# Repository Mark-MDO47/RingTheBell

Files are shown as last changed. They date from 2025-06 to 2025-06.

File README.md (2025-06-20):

# RingTheBell
Demo - use YX5200 to create sounds for the strongman carnival ring the bell game.

**Table Of Contents**
* [Top](#ringthebell "Top")
* [The Idea](#the-idea "The Idea")
  * [ESP32 Over-The-Air Update - OTA](#esp32-over\-the\-air-update-\--ota "ESP32 Over-The-Air Update - OTA")
* [Schematic](#schematic "Schematic")
  * [Nano/Uno - YX5200 PWR at 5V UART at 5V - Works Reliably](#nanouno-\--yx5200-pwr-at-5v-uart-at-5v-\--works-reliably "Nano/Uno - YX5200 PWR at 5V UART at 5V - Works Reliably")
  * [ESP32 - YX5200 PWR at 5V UART at 5V - Works Reliably](#esp32-\--yx5200-pwr-at-5v-uart-at-5v-\--works-reliably "ESP32 - YX5200 PWR at 5V UART at 5V - Works Reliably")
  * [ESP32 - YX5200 PWR at 5V UART at 3.3V - Not Reliable](#esp32-\--yx5200-pwr-at-5v-uart-at-33v-\--not-reliable "ESP32 - YX5200 PWR at 5V UART at 3.3V - Not Reliable")
  * [ESP32 - YX5200 PWR at 3.3V UART at 3.3V - Not Reliable](#esp32-\--yx5200-pwr-at-33v-uart-at-33v-\--not-reliable "ESP32 - YX5200 PWR at 3.3V UART at 3.3V - Not Reliable")
* [Code](#code "Code")
* [Sounds](#sounds "Sounds")
* [Parts List](#parts-list "Parts List")
  * [ESP32 version](#esp32-version "ESP32 version")
  * [Arduino NANO/UNO version](#arduino-nanouno-version "Arduino NANO/UNO version")

## The Idea
[Top](#ringthebell "Top")<br>
This will create sounds for the strongman carnival ring the bell game.

There will be two LOW-active inputs (either from buttons or another processor):
- when the mallet hits to start the weight climbing
- when the weight rings the bell at the top

It is silent until it sees the mallet hit.<br>
Then it starts a rising sound of finite duration.
- If the "ring the bell" input happens while the rising sound is active, the sound is interrupted and the ring the bell sound starts. That sound continues until it finishes.
- If the rising sound finishes before the "ring the bell" sound, then silence until another input happens.

There are two ways to compile, which use different I/O pins:
- as an ESP32 (but not ESP32-S3 which uses different pins; only exception I know)
- as an Arduino Nano or Uno

### ESP32 Over-The-Air Update - OTA
[Top](#ringthebell "Top")<br>
If compiled for an ESP32, the code will include the Over-The-Air Update (OTA) capability. By default, this is implemented so it is always-on, not requiring the ESP-NOW commands from the following descriptions (which are from other projects) nor the optional button push.
- https://github.com/Mark-MDO47/DuelWithBanjos/blob/master/code/DuelWithBanjos/OTA_story.md
- https://github.com/Mark-MDO47/UniRemote/blob/master/code/mdo_use_ota_webupdater/README.md

NOTE: The **Arduino Nano** and **Arduino Uno** do not natively support this OTA capability.

## Schematic
[Top](#ringthebell "Top")<br>
This "schematic wiring diagram" shows connections for both the Arduino Nano and an ESP32 development board.
- I sometimes call my schematics "schematic wiring diagrams" because I don't follow the rules of the standards organizations, although I reserve the right to just call them schematics.
  - I show all the connections as wires and show the pins of chips/modules all together and arranged the same as physical top view instead of separated/organized by function since I use my "schematic" to do the actual wiring of my project.
  - I tend to forget to hook up some of the power and ground connections if I use the standard schematic methods instead of showing the wire.

Notes
- I did not show a switch/button for the ESP32 OTA control signal since the code is configured to automatically prepare that without input
- The 1K resistor in the path to the YX5200 RX line prevents coupling of digital noise into the sound output
- I did not include external power for these prototype designs; I assume they will be powered from the USB
- I have a reliable version for Nano/Uno and for ESP32, plus two ESP32 variations that do now work reliably
  - The reliable ESP32 variation uses a SN74HCT125N to do voltage level translation for the UART interface
  - I am using resistors to drop the voltage from YX5200 5V to ESP32 3.3V (to avoid damage to ESP32)

### Nano/Uno - YX5200 PWR at 5V UART at 5V - Works Reliably
[Top](#ringthebell "Top")<br>
Here with a Nano/Uno and with the YX5200 using 5V for power and 5V on the UART interface - works reliably.<br>
```
// NANO (and UNO) pin definitions:
//
// Control inputs for Sound Processing - these two are GPIO pins with internal pull-up capability
//   NANO (or UNO) pin D-04   DPIN_MALLET_HIT  when it goes LOW
//   NANO (or UNO) pin D-06   DPIN_RING_BELL   when it goes LOW
//
// YX5200/DFPlayer Sound Player
//   NANO (or UNO) pin D-10   DPIN_SRL_RX   Arduino RX; YX5200 TX - 9600 Baud
//   NANO (or UNO) pin D-11   DPIN_SRL_TX   Arduino TX; YX5200 RX - 9600 Baud
//   NANO (or UNO) pin D-12   DPIN_AUDIO_BUSY YX5200 BUSY; HIGH when audio finishes
```
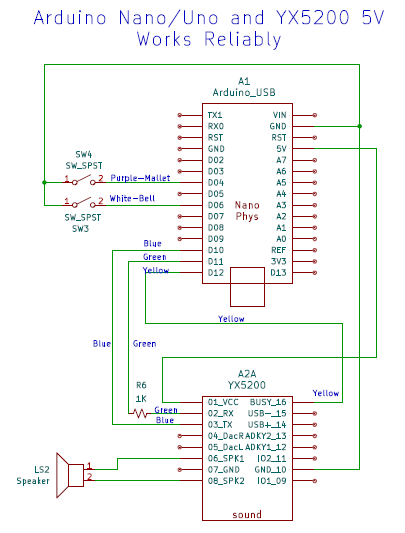
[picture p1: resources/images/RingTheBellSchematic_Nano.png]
Ring the Bell Schematic with Nano - works reliably


### ESP32 - YX5200 PWR at 5V UART at 5V - Works Reliably
[Top](#ringthebell "Top")<br>
Here with an ESP32 and with the YX5200 using 5V for power and 5V on the UART interface - works reliably.<br>
```
// ESP32 pin definitions:
//    NOTE: these are good pins for most ESP32 - see https://randomnerdtutorials.com/esp32-pinout-reference-gpios/
//    If using an ESP32-S3, see https://randomnerdtutorials.com/esp32-s3-devkitc-pinout-guide/ and make any
//       needed adjustments.
//
// Control inputs for Sound Processing - these two are GPIO pins with internal pull-up capability
//   ESP32 Dev Module pin D-13   DPIN_MALLET_HIT  when it goes LOW
//   ESP32 Dev Module pin D-27   DPIN_RING_BELL   when it goes LOW
// 
// YX5200/DFPlayer Sound Player
//   ESP32 Dev Module pin D-16   DPIN_SRL_RX   Arduino RX; YX5200 TX - 9600 Baud
//   ESP32 Dev Module pin D-17   DPIN_SRL_TX   Arduino TX; YX5200 RX - 9600 Baud
//   ESP32 Dev Module pin D-23   DPIN_AUDIO_BUSY YX5200 BUSY; HIGH when audio finishes
```
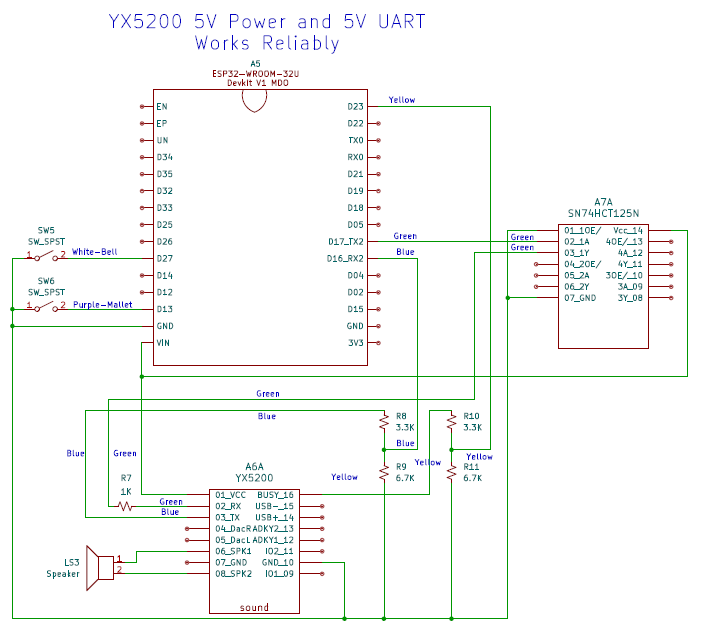
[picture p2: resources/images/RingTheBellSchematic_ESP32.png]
Ring the Bell Schematic with ESP32; YX5200 5V Power 5V UART - Works Reliably


### ESP32 - YX5200 PWR at 5V UART at 3.3V - Not Reliable
[Top](#ringthebell "Top")<br>
Here with an ESP32 and with the YX5200 using 5V for power and 3.3V on the UART interface - not reliable. The YX5200 often ignores commands from the ESP32.<br>
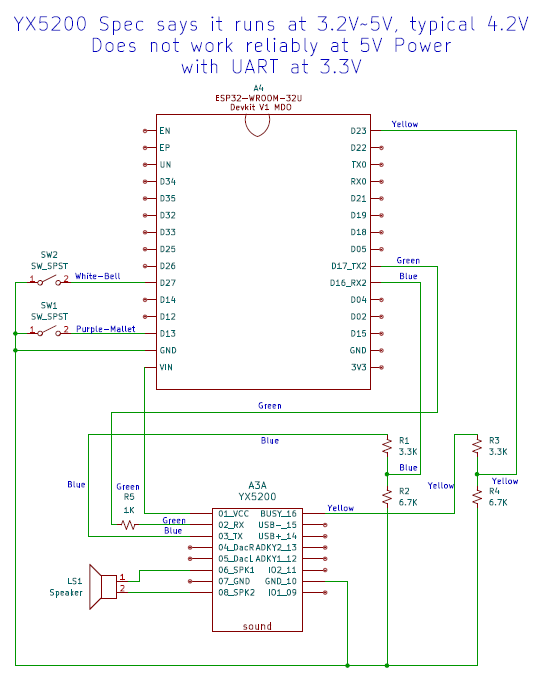
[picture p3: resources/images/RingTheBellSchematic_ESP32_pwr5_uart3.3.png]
Ring the Bell Schematic with ESP32; YX5200 5V Power 3.3V UART - Not Reliable


### ESP32 - YX5200 PWR at 3.3V UART at 3.3V - Not Reliable
[Top](#ringthebell "Top")<br>
Here with an ESP32 and with the YX5200 using 3.3V for power and 3.3V on the UART interface - not reliable. The YX5200 often ignores commands from the ESP32.<br>
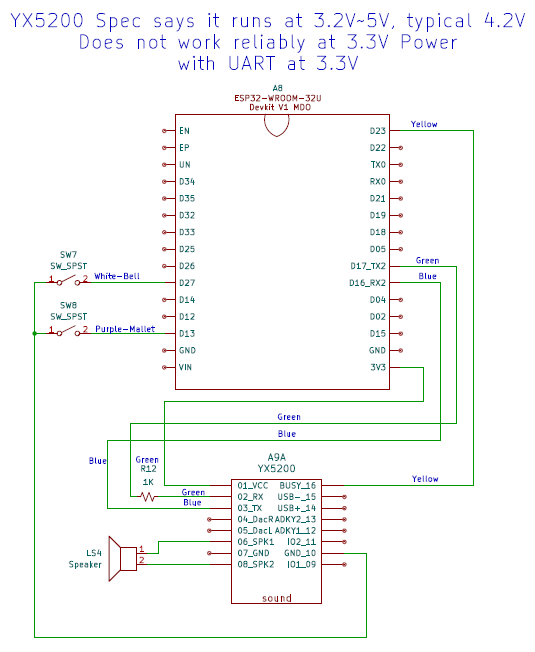
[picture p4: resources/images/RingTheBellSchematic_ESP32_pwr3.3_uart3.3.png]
Ring the Bell Schematic with ESP32; YX5200 3.3V Power 3.3V UART - Not Reliable


## Code
[Top](#ringthebell "Top")<br>
The code is in the ./code/ area split into several directories. The *.ino file is in ./code/RingTheBell/RingTheBell.ino.<br>
A directory of the code can be found here:
- https://github.com/Mark-MDO47/RingTheBell/tree/master/code

## Sounds
[Top](#ringthebell "Top")<br>
The sounds and a description of how to create/adjust sounds and how to copy them to the MicroSD card for the YX5200 can be found here:<br>
- https://github.com/Mark-MDO47/RingTheBell/blob/master/resources/sounds/README.md

## Parts List
[Top](#ringthebell "Top")<br>

### ESP32 version
[Top](#ringthebell "Top")<br>

| Title | Descrip | URL | each |
| --- | --- | --- | --- |
| ESP32 | 1 @ ESP32 Devkit V1 ESP-WROOM-32 (or just about any ESP32 WiFi capable module **except an ESP-32-S3**) | https://www.amazon.com/Hosyond-ESP-WROOM-32-Development-Microcontroller-Compatible/dp/B0C7C2HQ7P/ref=sr_1_4 | $3.50 |
| YX5200 | 1 @ Sound Module with MicroSD (TF) card socket | https://www.amazon.com/Organizer-YX5200-DFPlayer-Supporting-Arduino/dp/B07XXYQBNS/ref=sr_1_1 | $2.00 |
| MicroSD card | 1 @ 32GByte or smaller MicroSD card formatted as FAT32; shown is 16GB example | https://www.amazon.com/dp/B08KSSX9PH | $3.75 |
| speaker |  Metal Shell Round Internal Magnet Speaker 2W 8 Ohm approx 1 inch | https://www.amazon.com/dp/B0177ABRQ6 | $2.80 |
| resistors | 1 @ 1.0-KOhm 1/4 watt through-hole resistors | https://www.digikey.com/en/products/detail/stackpole-electronics-inc/CF14JT1K00/1741314 | $0.10 |
| resistors | 2 @ 3.3-KOhm 1/4 watt through-hole resistors | https://www.digikey.com/en/products/detail/stackpole-electronics-inc/CF14JT3K30/1741376 | $0.10 |
| resistors | 2 @ 6.65-KOhm 1/4 watt through-hole resistors | https://www.digikey.com/en/products/detail/stackpole-electronics-inc/RNF14FTD6K65/1682364 | $0.10 |
| SN74HCT125N | 1 @ Non-inverting 5.5V buffer 14-pin DIP | https://www.digikey.com/en/products/detail/texas-instruments/SN74HCT125N/376860 | $0.63 |

### Arduino NANO/UNO version
[Top](#ringthebell "Top")<br>

| Title | Descrip | URL | each |
| --- | --- | --- | --- |
| NANO | Arduino NANO (or UNO) or clone | https://www.aliexpress.us/item/3256805941736729.html | $1.40 |
| YX5200 | 1 @ Sound Module with MicroSD (TF) card socket | https://www.amazon.com/Organizer-YX5200-DFPlayer-Supporting-Arduino/dp/B07XXYQBNS/ref=sr_1_1 | $2.00 |
| MicroSD card | 1 @ 32GByte or smaller MicroSD card formatted as FAT32; shown is 16GB example | https://www.amazon.com/dp/B08KSSX9PH | $3.75 |
| speaker |  Metal Shell Round Internal Magnet Speaker 2W 8 Ohm approx 1 inch | https://www.amazon.com/dp/B0177ABRQ6 | $2.80 |
| resistors | 1 @ 1.0-KOhm 1/4 watt through-hole resistors | https://www.digikey.com/en/products/detail/stackpole-electronics-inc/CF14JT1K00/1741314 | $0.10 |

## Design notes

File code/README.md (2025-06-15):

# Code

**Table Of Contents**
* [Top](#code "Top")
* [Introduction](#introduction "Introduction")
* [RingTheBell](#ringthebell "RingTheBell")
* [lib_commonDFcode](#lib_commondfcode "lib_commonDFcode")
* [lib_DFPlayerMini](#lib_dfplayermini "lib_DFPlayerMini")
* [lib_mdo_use_ota](#lib_mdo_use_ota "lib_mdo_use_ota")

## Introduction
[Top](#code "Top")<br>
The code is divided into several subdirectories as shown below<br>
| Directory | Description |
| --- | --- |
| [code/RingTheBell](https://github.com/Mark-MDO47/RingTheBell/tree/master/code/RingTheBell "RingTheBell - the *.ino containing #defines to define compile options") | The *.ino file for RingTheBell.<br>  Has #define statements to control choice of Arduino NANO/UNO or ESP32 target.<br>  **void DFsetup_pins_serial()** - defines pins and inits serial port for YX5200 DFPlayer. Includes code that handles SoftwareSerial for Arduino NANO/UNO and Hardware Serial for ESP32. |
| [code/lib_commonDFcode](https://github.com/Mark-MDO47/RingTheBell/tree/master/code/lib_commonDFcode "lib_commonDFcode") | lib_commonDFcode - This is where (almost all) the routines are that I wrote to handle calls to DFPlayerMini. Significant ones are<br>  **void DFsetup()** - call after calling **DFsetup_pins_serial**; will set baud rate to 9600 internally, choose SD card operation, and set default volume.<br>  **void  DFstartSound(uint16_t p_SoundNum, uint16_t p_Volume)** - starts requested *.wav file, interrupting any playing sound file. Also sets volume level.<br>  **uint8_t DFcheckSoundDone()** - returns TRUE if previous sound is complete. Takes into account that HW BUSY signal may not start until >=40 milliseconds after DFstartSound(). |
| [code/lib_DFPlayerMini](https://github.com/Mark-MDO47/RingTheBell/tree/master/code/lib_DFPlayerMini "lib_DFPlayerMini") | lib_DFPlayerMini - The source code for the DFRobot driver for the DFPlayer module.<br>  Available with Arduino IDE but I did a lot of debugging over the years inserting modified code here so I just always include it.<br>  Has its own separate license in file LICENSE_for_DFRobot_code.txt |
| [code/lib_mdo_use_ota](https://github.com/Mark-MDO47/RingTheBell/tree/master/code/lib_mdo_use_ota "lib_mdo_use_ota") | lib_mdo_use_ota - My ESP32 Over-The-Air Update (OTA) code to make it easy to use OTA.<br>  Originally from https://github.com/Mark-MDO47/UniRemote/tree/master/code/mdo_use_ota_webupdater |

## RingTheBell
[Top](#code "Top")<br>

### ESP32 Over-The-Air Update - OTA
[Top](#code "Top")<br>
If compiled for an ESP32, the code will include the Over-The-Air Update (OTA) capability. By default, this is implemented so it is always-on, not requiring the ESP-NOW commands from the following descriptions (which are from other projects) nor the optional button push.
- https://github.com/Mark-MDO47/DuelWithBanjos/blob/master/code/DuelWithBanjos/OTA_story.md
- https://github.com/Mark-MDO47/UniRemote/blob/master/code/mdo_use_ota_webupdater/README.md

ESP32 OTA compilation is controlled by the following **#define** statements in **RingTheBell.ino**
```C
#define MDO_USE_OTA  1 // zero to not use, non-zero to use OTA ESP32 Over-The-Air software updates
#define FORCE_OTA_ON_IF 1 // ESP32: non-zero to force OTA to be on always without needing the pin ONLY if MDO_USE_OTA is also on
```

If you want to compile for ESP32 with OTA enabled you need to create a file **gitignore_wifi_key.h** with the following definitions (I suggest using the ".gitignore" file so this does not accidentally show up in your public repository; see below after the #define statements).
```C
#define WIFI_PWD "password for your local wifi"
#define WIFI_SSID "SSID for your local WiFi"
#define WIFI_OTA_WEB_USR "username to be able to do OTA"
#define WIFI_OTA_WEB_PWD "password to be able to do OTA"
```

You could optionally add this line at the end of your **.gitignore** file to prevent any file or directory starting with gitignore from being saved to the repository. Can save some embarassment.
```
gitignore*
```

NOTE: The **Arduino Nano** and **Arduino Uno** do not natively support this OTA capability.

## lib_commonDFcode
[Top](#code "Top")<br>

## lib_DFPlayerMini
[Top](#code "Top")<br>

## lib_mdo_use_ota
[Top](#code "Top")<br>
This code is an attempt to make the ESP32 Over-The-Air Update (OTA) capability easy to use. It comes from my UniRemote project. Details can be found here:
- https://github.com/Mark-MDO47/UniRemote/tree/master/code/mdo_use_ota_webupdater

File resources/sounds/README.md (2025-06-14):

# Ring the Bell Sounds

**Table Of Contents**
* [Top](#ring-the-bell-sounds "Top")
* [Audacity](#audacity "Audacity")
* [FreeSound](#freesound "FreeSound")
* [YX5200 DFplayer](#yx5200-dfplayer "YX5200 DFplayer")
* [Creating and Modifying Sound Files](#creating-and-modifying-sound-files "Creating and Modifying Sound Files")
  * [Generate Chirp](#generate-chirp "Generate Chirp")
  * [After Generate Chirp](#after-generate-chirp "After Generate Chirp")
  * [Export Chirp](#export-chirp "Export Chirp")
  * [Generate Silence](#generate-silence "Generate Silence")
  * [Export Silence](#export-silence "Export Silence")
  * [Import Mr. Fossy](#import-mr-fossy "Import Mr. Fossy")
  * [Export Mr. Fossy](#export-mr-fossy "Export Mr. Fossy")
* [Copy the Files to MicroSD Card](#copy-the-files-to-microsd-card "Copy the Files to MicroSD Card")

## Audacity
[Top](#ring-the-bell-sounds "Top")<br>
I used Audacity to create and/or manipulate the sound files to a format usable by the YX5200 audio chip.
- https://www.audacityteam.org/

## FreeSound
[Top](#ring-the-bell-sounds "Top")<br>
I obtained one file from FreeSound that I didn't create with Audacity.
- https://freesound.org

This sound was SFX_STICKERRIPPER_foilBooms_01.wav found at https://freesound.org/people/MrFossy/sounds/590360/. It was generated by a user named "MrFossy".
- I will refer to any sound file with a derivation from this sound by the name "Mr. Fossy".
- In the text relating to this file on FreeSound it says
```
Feel free to use my sounds for any commercial/noncommercial purpose without attribution.
 (I wouldn't object to being credited, however!)
```

Thank you MrFossy!

## YX5200 DFplayer
[Top](#ring-the-bell-sounds "Top")<br>
Using the YX5200 to read the sound files and drive the 8-ohm speaker.

This repo has a lot of info on making .wav files that are suitable for the YX5200. I use .wav instead of .mp3 both because it works better with more clones of the YX5200 and because there is a noticeable start-up delay with .mp3 files.
- https://github.com/Mark-MDO47/AudioPlayer-YX5200

## Creating and Modifying Sound Files
[Top](#ring-the-bell-sounds "Top")<br>

### Generate Chirp
[Top](#ring-the-bell-sounds "Top")<br>
Menu: **Generate** ==> **Chirp...** then use the settings shown.<br>
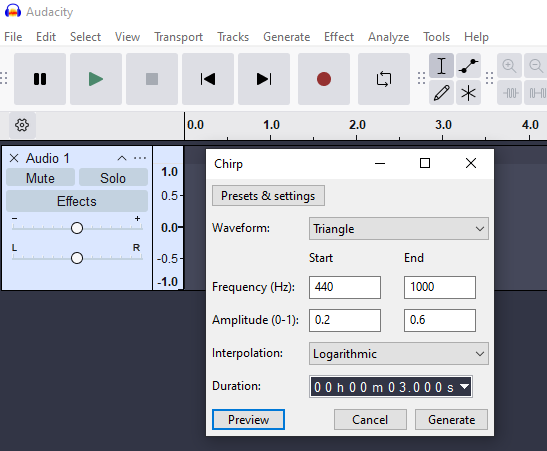
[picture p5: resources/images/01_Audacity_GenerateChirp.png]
Audacity Generate Chirp


### After Generate Chirp
[Top](#ring-the-bell-sounds "Top")<br>
You can see the gradual crescendo.<br>
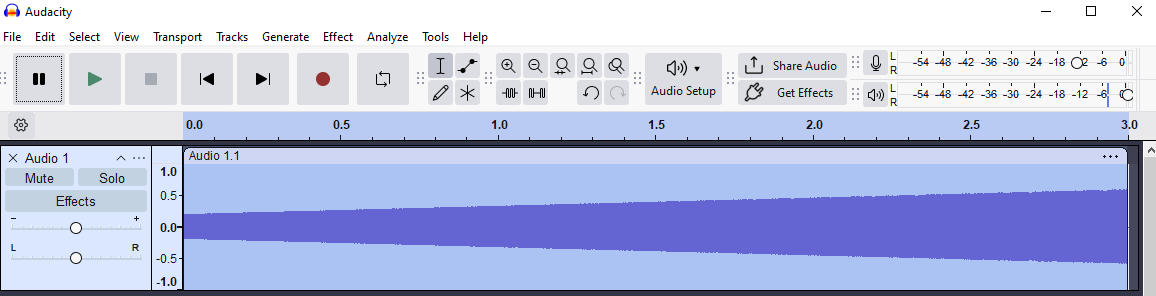
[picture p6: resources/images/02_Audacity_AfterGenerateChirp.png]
Audacity After Generate Chirp


### Export Chirp
[Top](#ring-the-bell-sounds "Top")<br>
We save it as a 22050 Hz mono .wav file; see https://github.com/Mark-MDO47/AudioPlayer-YX5200 for the reason.<br>
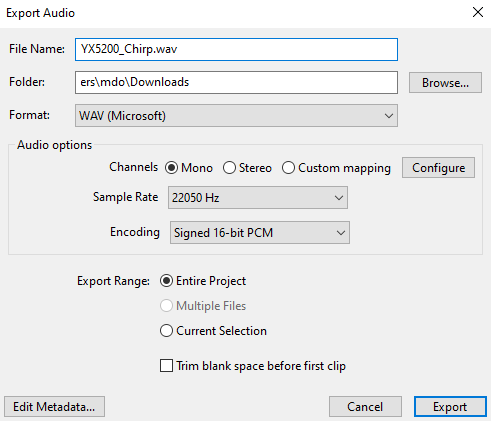
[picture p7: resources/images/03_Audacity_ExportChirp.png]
Audacity Export Chirp.png


### Generate Silence
[Top](#ring-the-bell-sounds "Top")<br>
Menu: **Generate** ==> **Silence...** then use the settings shown.<br>
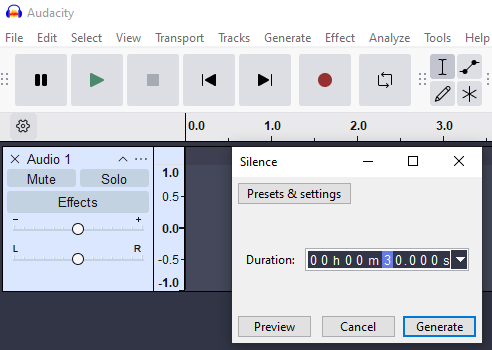
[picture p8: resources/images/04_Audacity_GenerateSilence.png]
Audacity Generate Silence


### Export Silence
[Top](#ring-the-bell-sounds "Top")<br>
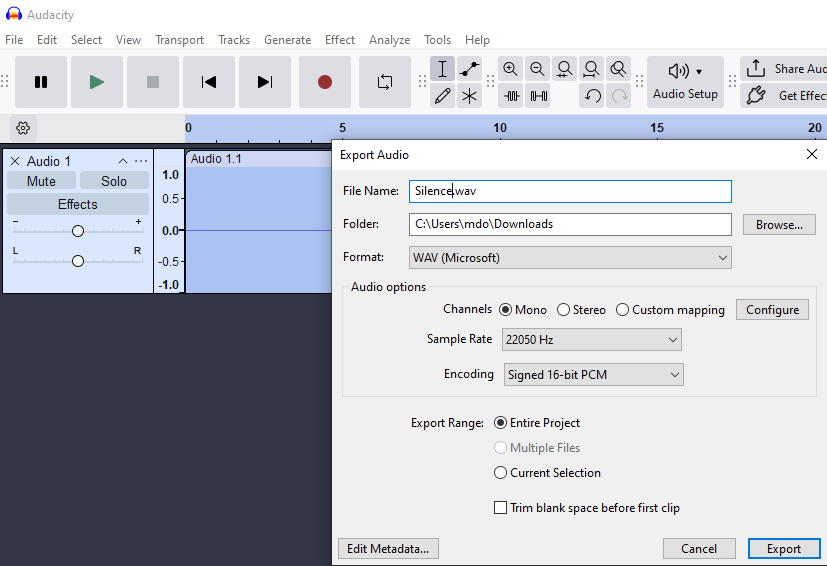
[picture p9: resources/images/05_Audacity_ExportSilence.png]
Audacity Export Silence


### Import Mr. Fossy
[Top](#ring-the-bell-sounds "Top")<br>
Menu: **File** ==> **Import** ==> **Audio...** and choose the file.<br>
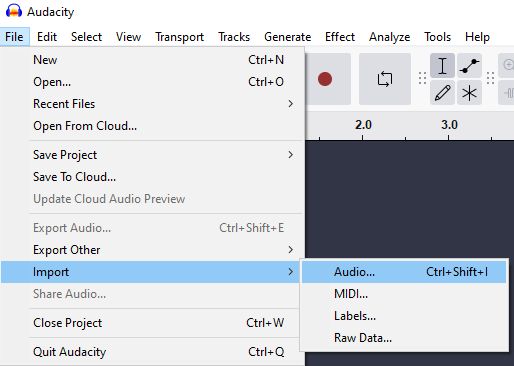
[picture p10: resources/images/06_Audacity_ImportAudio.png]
Audacity Import Mr. Fossy Audio


### Export Mr. Fossy
[Top](#ring-the-bell-sounds "Top")<br>
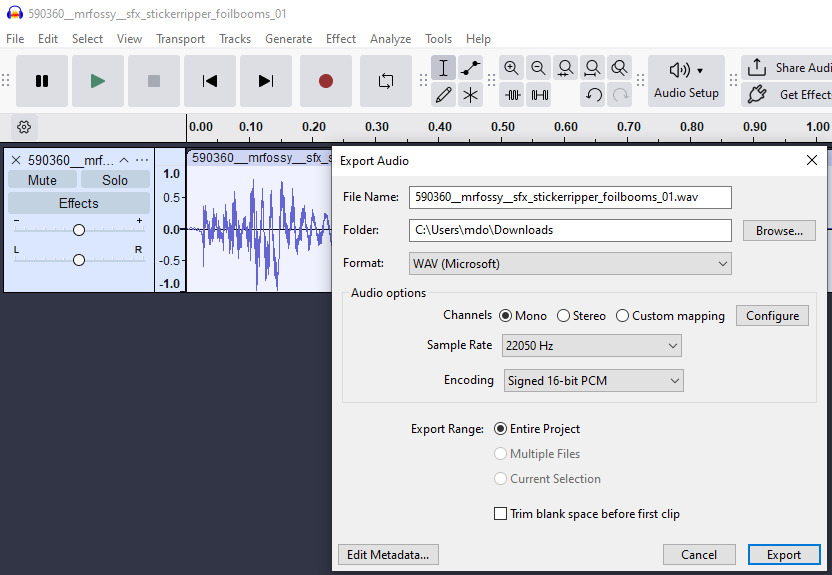
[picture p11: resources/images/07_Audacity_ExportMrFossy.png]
Audacity Export Mr. Fossy Audio


## Copy the Files to MicroSD Card
[Top](#ring-the-bell-sounds "Top")<br>
The MicroSD card **must** be freshly formatted as FAT32; see https://github.com/Mark-MDO47/AudioPlayer-YX5200

Also from that reference, use copyem.py to create a list of commands to copy the files in correct order onto the MicroSD card.
- I use GIT bash on Windows to do this; my script is run_copyem.sh which assumes
  - the freshly FAT32-formatted MicroSD card is mounted as H: (Windows)
  - I am running the script from the directory containing the .wav files
  - that same directory contains Attributions.html file that I want stored on the MicroSD card
  - I want the output as a bash script not a Windows .bat format
  - once again, I suggest you look at https://github.com/Mark-MDO47/AudioPlayer-YX5200 for more details

You could either just let the commands show up on the screen and copy/paste them back into the GIT bash screen, but run_copyem.sh redirects them to file copy_files.sh.

Here is what my script run_copyem.sh looks like:<br>
```
python /d/github-Mark-MDO47/AudioPlayer-YX5200/copyem.py -d . -s H: -f 0003_YX5200_Silence.wav -l > copy_files.sh
```

Here is what the output script copy_files.sh looks like:<br>
```
cp ./0001_yx5200_chirp.wav H:/001.wav
cp ./0002_yx5200_mrfossy__sfx_stickerripper_foilbooms_01.wav H:/002.wav
cp ./0003_yx5200_silence.wav H:/003.wav

mkdir H:/ATTRIBUTIONS
cp  ./Attributions.html H:/ATTRIBUTIONS
```

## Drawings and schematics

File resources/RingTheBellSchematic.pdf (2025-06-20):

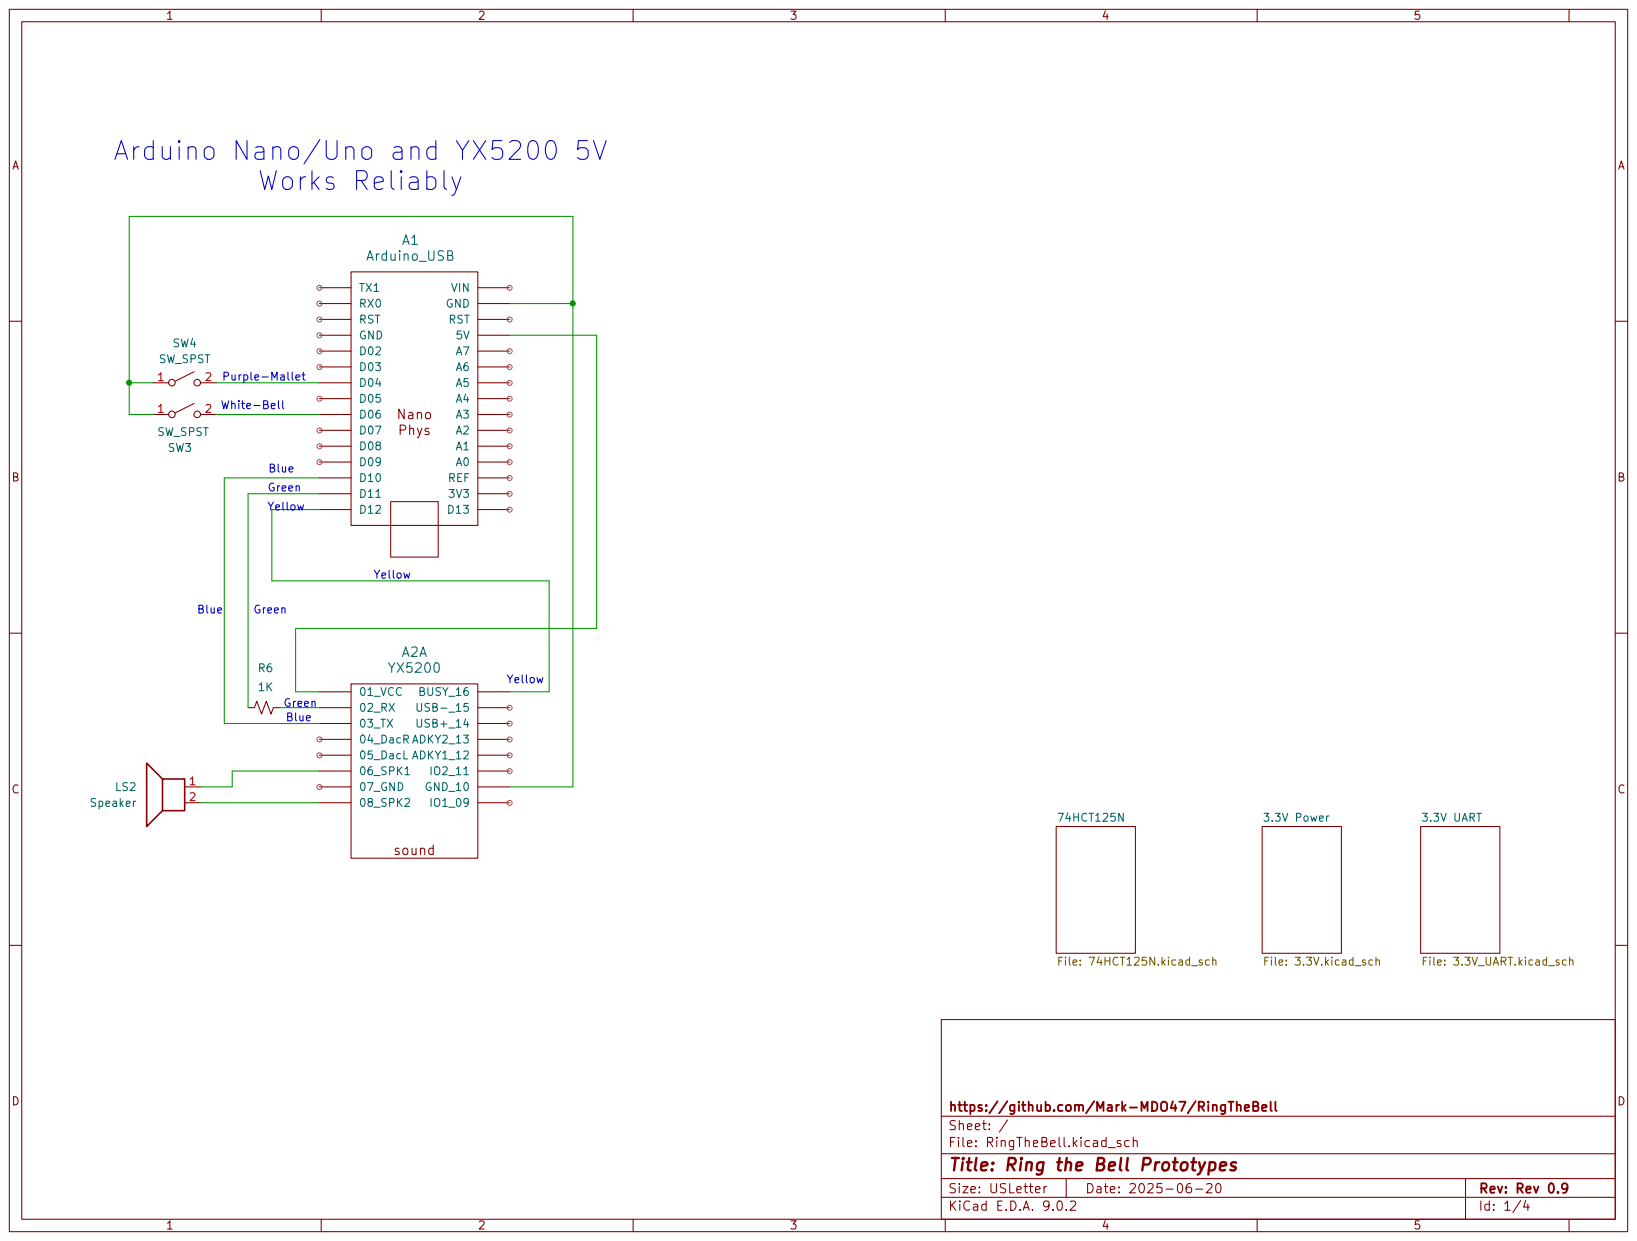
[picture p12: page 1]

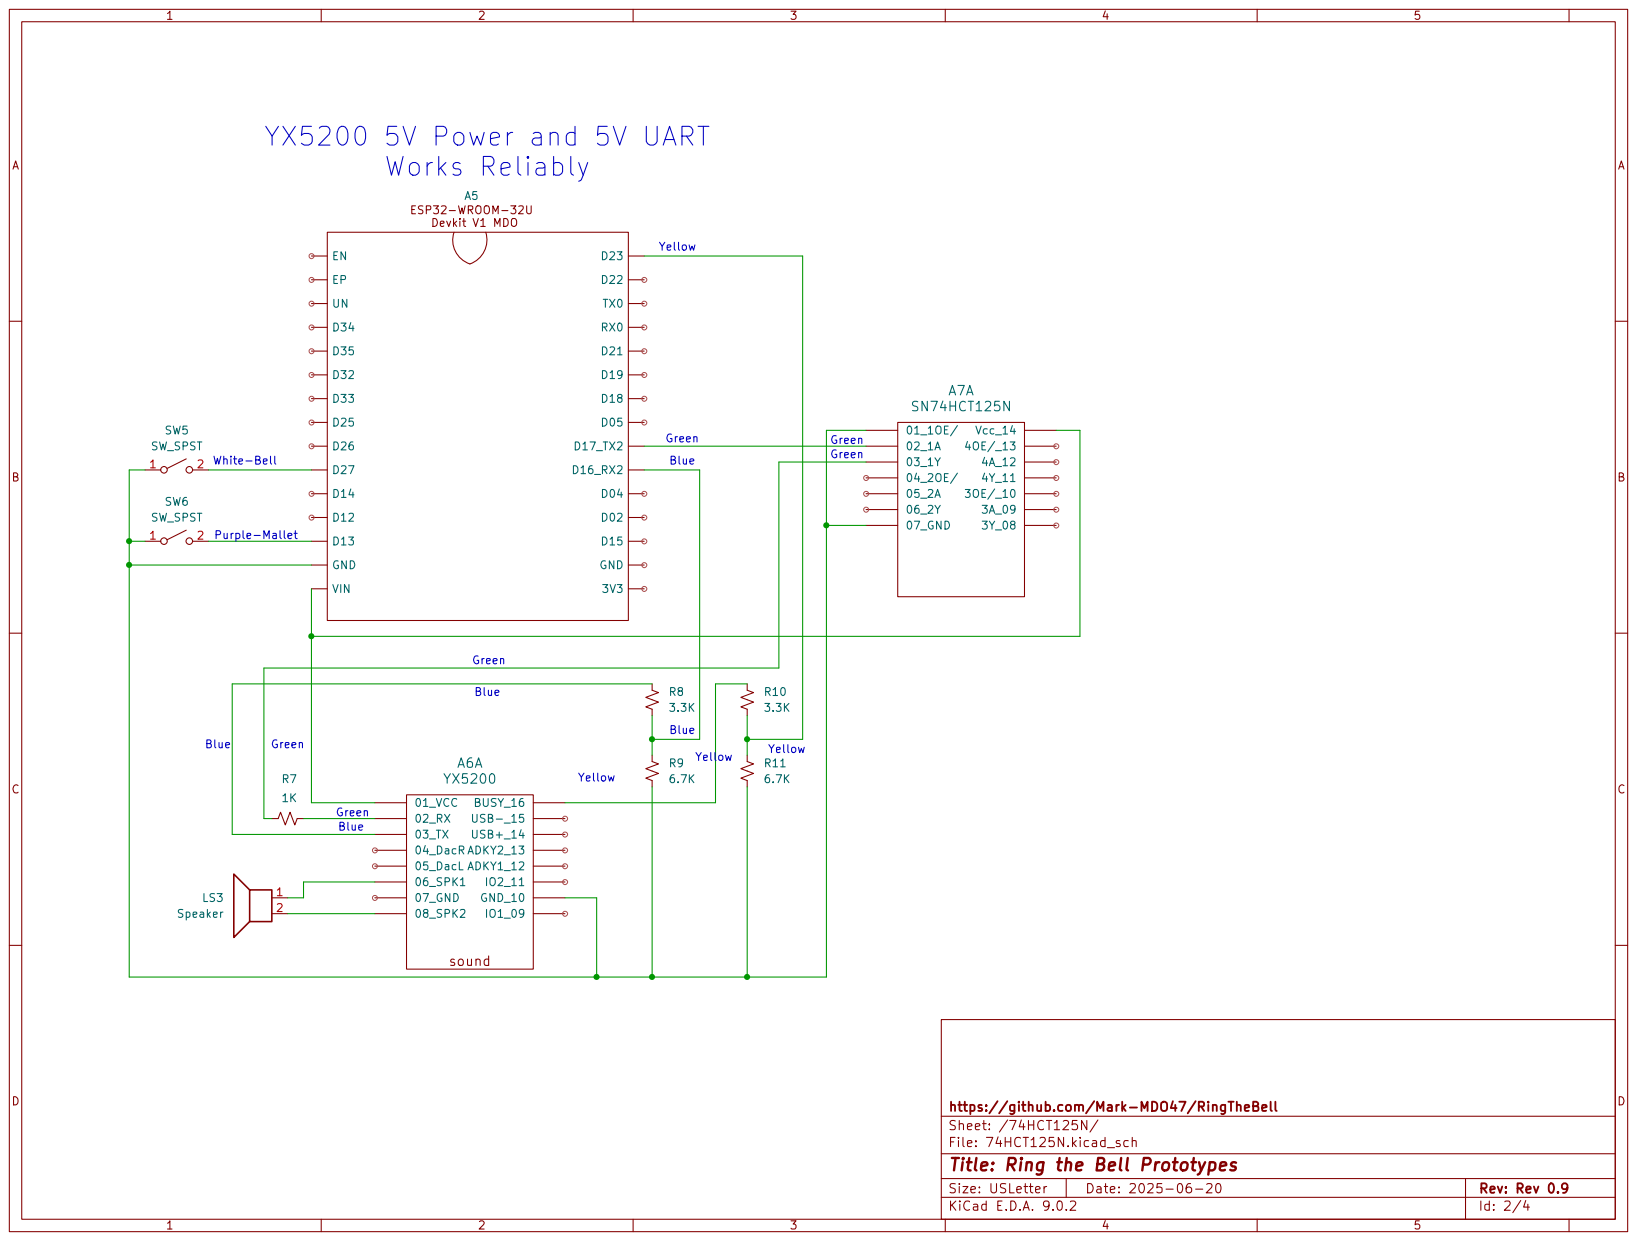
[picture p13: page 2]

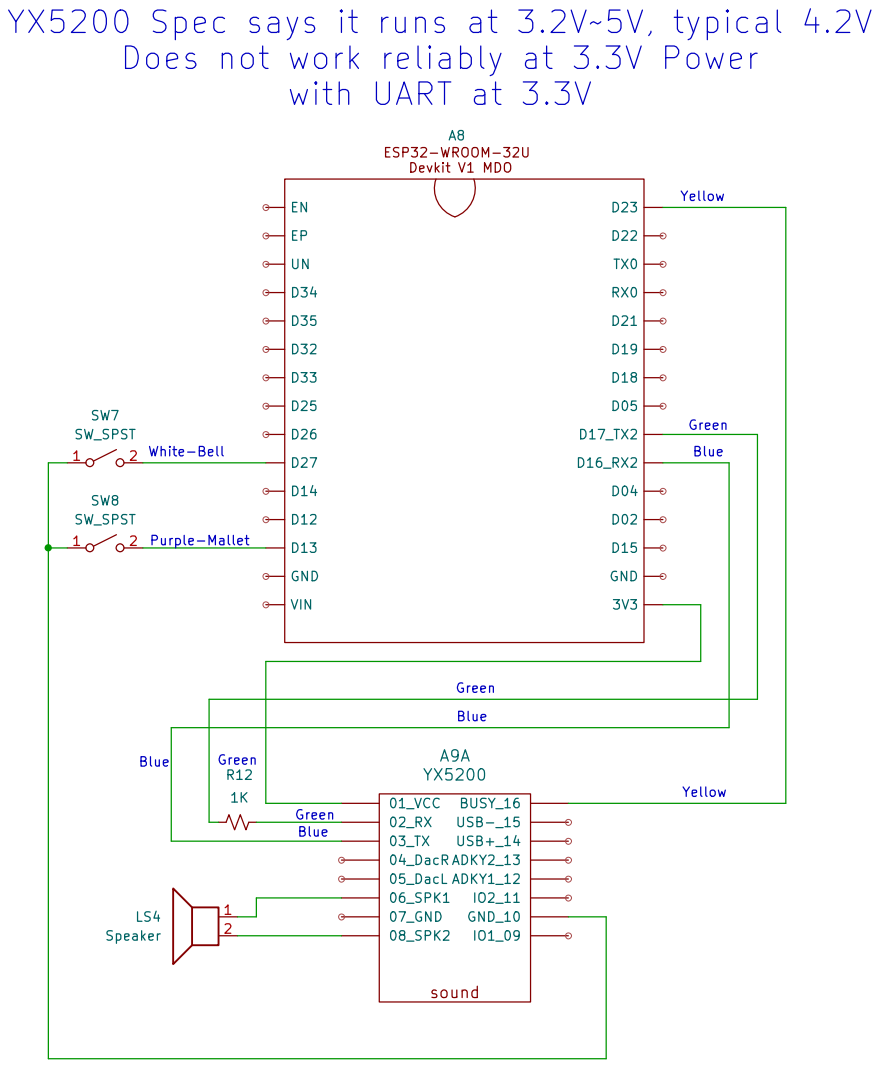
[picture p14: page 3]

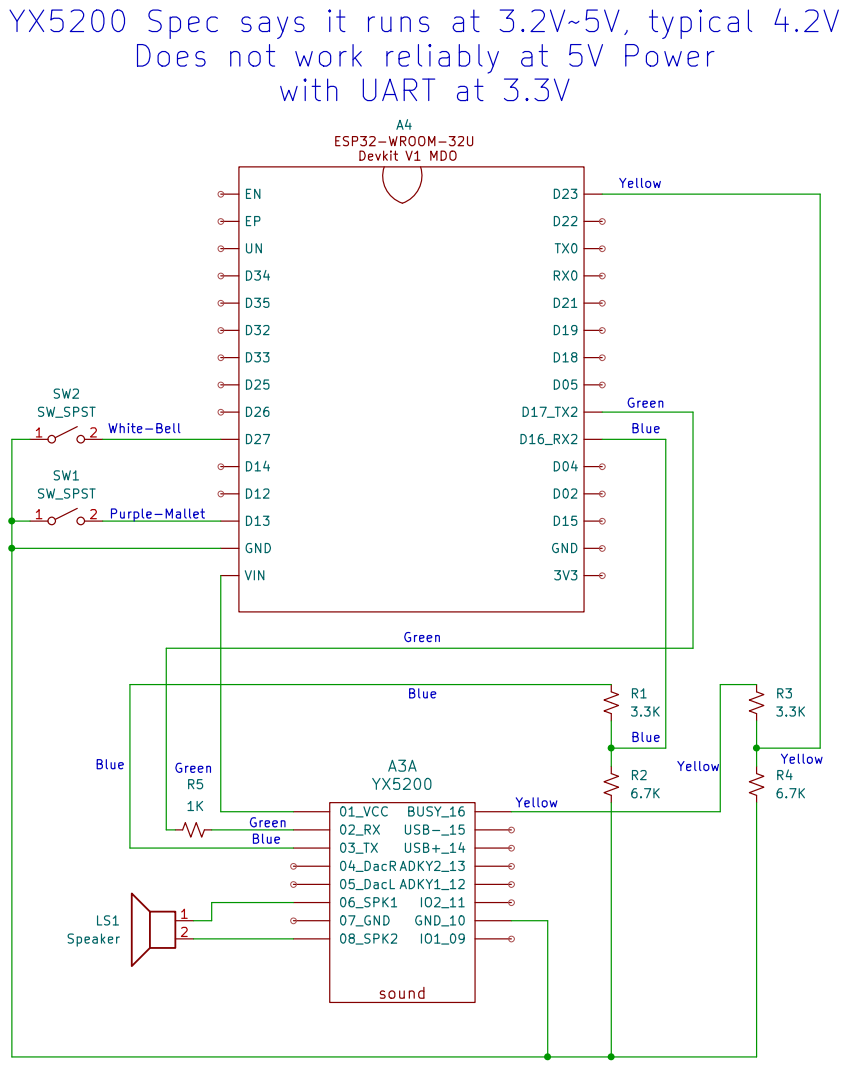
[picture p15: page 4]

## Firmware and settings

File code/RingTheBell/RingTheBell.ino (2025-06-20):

// RingTheBell 2025
// Author: https://github.com/Mark-MDO47/
//
// https://github.com/Mark-MDO47/RingTheBell
//

/*
   Copyright 2025 Mark Olson

   Licensed under the Apache License, Version 2.0 (the "License");
   you may not use this file except in compliance with the License.
   You may obtain a copy of the License at

       http://www.apache.org/licenses/LICENSE-2.0

   Unless required by applicable law or agreed to in writing, software
   distributed under the License is distributed on an "AS IS" BASIS,
   WITHOUT WARRANTIES OR CONDITIONS OF ANY KIND, either express or implied.
   See the License for the specific language governing permissions and
   limitations under the License.
 */

#include "Arduino.h"                // general Arduino definitions plus uint8_t etc.


////////////////////////////////////////////////////////////////////////////////////////
//
// This can compile either for either Arduino Nano/Uno or ESP32 (not ESP32-S3; would need to check pin assignments)
// The pin definitions are necessarily different for ESP32 and NANO/UNO compiles.
//    I have not added definitions for ESP32-S3, which is probably different than the ESP32 pins.
//
// If compiled for Nano, OTA (Over-The-Air update) is not available.

#define COMPILE_AS_ESP32 1 // only one of these can be 1; the other must be 0
#define COMPILE_AS_NANO  0 // only one of these can be 1; the other must be 0

////////////////////////////////////////////////////////////////////////////////////////



////////////////////////////////////////////////////////////////////////////////////////
// YX5200 related info
//
// Attributions for the sounds are on the MicroSD card containing the sounds.
// The sounds are either obtained from https://freesound.org/ or else generated by me using Audacity https://www.audacityteam.org/

// See https://github.com/Mark-MDO47/AudioPlayer-YX5200 for details on using the YX5200/DFPlayer.
//   I usually install a copy of the DFRobot.com DFPlayer code when using it, since I did a lot
//   of debugging to find how to use it on all the variants of the YX5200 I have seen.
//   The still unmodified DFRobot.com DFPlayer code files are DFRobotDFPlayerMini.*.
//   LICENSE_for_DFRobot_code.txt shows it is OK to do this and describes the legal boundaries
//   for correct usage.
////////////////////////////////////////////////////////////////////////////////////////



////////////////////////////////////////////////////////////////////////////////////////
// Delay definitions

#define LOOP_DELAY_MSEC       20  // milliseconds; this delay should be less than one-half of MIN_DEBOUNCE_MSEC
#define MIN_DEBOUNCE_MSEC    120  // milliseconds to debounce control inputs
#define SOUND_ACTIVE_PROTECT 200  // milliseconds to keep YX5200 SW twiddled sound active after doing myDFPlayer.play(mySound)

////////////////////////////////////////////////////////////////////////////////////////


////////////////////////////////////////////////////////////////////////////////////////
// ESP32 pin definitions:
//    NOTE: these are good pins for most ESP32 - see https://randomnerdtutorials.com/esp32-pinout-reference-gpios/
//    If using an ESP32-S3, see https://randomnerdtutorials.com/esp32-s3-devkitc-pinout-guide/ and make any
//       needed adjustments.
//
// Control inputs for Sound Processing - these two are GPIO pins with internal pull-up capability
//   ESP32 Dev Module pin D-13   DPIN_MALLET_HIT  when it goes LOW
//   ESP32 Dev Module pin D-27   DPIN_RING_BELL   when it goes LOW
// 
// YX5200/DFPlayer Sound Player
//   ESP32 Dev Module pin D-16   DPIN_SRL_RX   Arduino RX; YX5200 TX - 9600 Baud
//   ESP32 Dev Module pin D-17   DPIN_SRL_TX   Arduino TX; YX5200 RX - 9600 Baud
//   ESP32 Dev Module pin D-23   DPIN_AUDIO_BUSY YX5200 BUSY; HIGH when audio finishes
//
// For ESP32 only: this can be updated via LOW-pulse on DPIN_OTA, which will cause us to open a
//      web page on the specified SSID allowing Over-The-Air software update.
//   That capability is based on the ESP32 example OTAWebUpdater.ino, with my tweaks.
//
// Control inputs for OTA update
//   ESP32 Dev Module pin D-22   DPIN_OTA         when it goes LOW
//
////////////////////////////////////////////////////////////////////////////////////////


////////////////////////////////////////////////////////////////////////////////////////
// NANO (and UNO) pin definitions:
//
// Control inputs for Sound Processing - these two are GPIO pins with internal pull-up capability
//   NANO (or UNO) pin D-04   DPIN_MALLET_HIT  when it goes LOW
//   NANO (or UNO) pin D-06   DPIN_RING_BELL   when it goes LOW
//
// YX5200/DFPlayer Sound Player
//   NANO (or UNO) pin D-10   DPIN_SRL_RX   Arduino RX; YX5200 TX - 9600 Baud
//   NANO (or UNO) pin D-11   DPIN_SRL_TX   Arduino TX; YX5200 RX - 9600 Baud
//   NANO (or UNO) pin D-12   DPIN_AUDIO_BUSY YX5200 BUSY; HIGH when audio finishes
//
////////////////////////////////////////////////////////////////////////////////////////


////////////////////////////////////////////////////////////////////////////////////////
#if COMPILE_AS_ESP32
// mdo_use_ota_webupdater https://github.com/Mark-MDO47/UniRemote/tree/master/code/mdo_use_ota_webupdater
// This does not connect to WiFi router until it gets turned on
#define MDO_USE_OTA  1 // zero to not use, non-zero to use OTA ESP32 Over-The-Air software updates
#define FORCE_OTA_ON_IF 1 // ESP32: non-zero to force OTA to be on always without needing the pin ONLY if MDO_USE_OTA is also on

#if MDO_USE_OTA
#include "../lib_mdo_use_ota/mdo_use_ota_webupdater.h"   // for mdo_use_ota_webupdater "library"
#include "../lib_mdo_use_ota/mdo_use_ota_webupdater.cpp" // for mdo_use_ota_webupdater "library"
#define FORCE_OTA_ON FORCE_OTA_ON_IF // DO NOT EDIT THIS - keep choice above
#else // not MDO_USE_OTA
#define FORCE_OTA_ON 0 // DO NOT EDIT THIS - don't allow mistake
#endif // MDO_USE_OTA

#include "HardwareSerial.h"         // to talk with the YX5200 - ESP32 uses hardware serial port

////////////////////////////////////////////////////////////////////////////////////////
// pins for Control Inputs
// NOTE: If using computer to control these pins, either adjust the LOOP_DELAY_MSEC above
//           or else adjust your control timing per the following:
//       You must hold control signals LOW for at least 2.5 * LOOP_DELAY_MSEC to ensure
//           correct operation. Nyquist says 2 but common sense says add a smidgeon.
//           We could actually catch the edge with a factor of 1.5 but overkill is authorized.
//       A human pressing a button will almost certainly meet this criteria.

#define DPIN_MALLET_HIT 13 // ESP32: goes LOW to start the Mallet Hit and rising sound SOUNDNUM_MalletHit
#define DPIN_RING_BELL  27 // ESP32: goes LOW to start the bell ringing sound SOUNDNUM_RingBell

#if MDO_USE_OTA // if using Over-The-Air software updates
#define DPIN_OTA        22 // ESP32: goes LOW to start the OTA web server
#endif // MDO_USE_OTA // if using Over-The-Air software updates

////////////////////////////////////////////////////////////////////////////////////////
// pins for YX5200/DFPlayer

#define DPIN_SRL_RX   16  // HW-serial in  - talk to DFPlayer audio player (YX5200)
#define DPIN_SRL_TX   17  // HW-serial out - talk to DFPlayer audio player (YX5200)
#define DPIN_AUDIO_BUSY 23  // digital input - HIGH when audio finishes

#endif // COMPILE_AS_ESP32
////////////////////////////////////////////////////////////////////////////////////////



////////////////////////////////////////////////////////////////////////////////////////
#if COMPILE_AS_NANO
#define MDO_USE_OTA 0  // Nano/Uno has no OTA ESP32 Over-The-Air software updates
#define FORCE_OTA_ON 0 // Nano/Uno has no OTA ESP32 Over-The-Air software updates

#include "SoftwareSerial.h"  // to talk to myDFPlayer without using up debug serial port

////////////////////////////////////////////////////////////////////////////////////////
// pins for Control Inputs
// NOTE: If using computer to control these pins, either adjust the LOOP_DELAY_MSEC above
//           or else adjust your control timing per the following:
//       You must hold control signals LOW for at least 2.5 * LOOP_DELAY_MSEC to ensure
//           correct operation. Nyquist says 2 but common sense says add a smidgeon.
//           We could actually catch the edge with a factor of 1.5 but overkill is authorized.
//       A human pressing a button will almost certainly meet this criteria.

#define DPIN_MALLET_HIT 4 // Nano/Uno: goes LOW to start the Mallet Hit and rising sound SOUNDNUM_MalletHit
#define DPIN_RING_BELL  6 // Nano/Uno: goes LOW to start the bell ringing sound SOUNDNUM_RingBell

////////////////////////////////////////////////////////////////////////////////////////
// pins for YX5200/DFPlayer

#define DPIN_SRL_RX     10  // Nano/Uno: SW-serial in  - talk to DFPlayer audio player (YX5200)
#define DPIN_SRL_TX     11  // Nano/Uno: SW-serial out - talk to DFPlayer audio player (YX5200)
#define DPIN_AUDIO_BUSY 12  // Nano/Uno: digital input - HIGH when audio finishes

SoftwareSerial mySoftwareSerial(DPIN_SRL_RX, DPIN_SRL_TX); // to talk to YX5200 audio player

#endif // COMPILE_AS_NANO


////////////////////////////////////////////////////////////////////////////////////////
// definitions for YX5200/DFPlayer

uint32_t gTimerForceSoundActv = 0;  // SOUND_ACTIVE_PROTECT until millis() >= this

#include "SoundNum.h"               // numbers for each sound
#include "../lib_DFPlayerMini/DFRobotDFPlayerMini.h"    // to communicate with the YX5200 audio player
#include "../lib_DFPlayerMini/DFRobotDFPlayerMini.cpp"  // to communicate with the YX5200 audio player
DFRobotDFPlayerMini myDFPlayer;                         // to talk to YX5200 audio player
void DFsetup();                                         // how to initialize myDFPlayer

#define SOUND_VOL_MIN      0   // range 0 to 30
#define SOUND_VOL_MAX      30  // range 0 to 30
#define SOUND_VOL_DEFAULT  25  // default volume - range 0 to 30

// #define DFPRINTDETAIL 1 // if need detailed status from myDFPlayer (YX5200 communications)
#define DFPRINTDETAIL 0  // will not print detailed status from myDFPlayer

#if DFPRINTDETAIL // routine to do detailed debugging
  void DFprintDetail(uint8_t type, int value); // definition of call
#else  // no DFPRINTDETAIL
  #define DFprintDetail(type, value) // nothing at all
#endif // #if DFPRINTDETAIL

#include "../lib_commonDFcode/lib_commonDFcode.cpp" // separated so the essence can be viewed as a piece
//   DFsetup(); - call from setup() routine; does everything except setup pins and serial
//   DFstartSound(uint16_t p_SoundNum, uint16_t p_Volume); - starts new sound even if currently playing a sound
//   DFcheckSoundDone(); - returns TRUE if current sound is complete
//   DFprintDetail(uint8_t type, int value); - optional routine to break out error code onto Serial

/////////////////////////////////////////////////////////////////////////////////////////////////////////
// DFsetup_pins_serial() - connect YX5200 to hardware pins and serial resources
//    Done here so the hardware differences are visible, not hidden in lib_commonDFcode.cpp
//
// NOTE: DPIN_AUDIO_BUSY must be capable of INPUT_PULLUP operation
//
void DFsetup_pins_serial() {
  pinMode(DPIN_AUDIO_BUSY,  INPUT_PULLUP); // HIGH when audio stops

  // ESP32 and NANO versions of code
  //    start serial port at 9600
  //    start communications with myDFPlayer YX5200; see if it is happy
#if COMPILE_AS_ESP32
  Serial2.begin(9600, SERIAL_8N1, DPIN_SRL_RX, DPIN_SRL_TX); // this is ESP32 control to DFPlayer audio player 
  if (!myDFPlayer.begin(Serial2, false, true))  // ESP32 uses Serial2 to communicate with YX5200
#endif // #if COMPILE_AS_ESP32
#if COMPILE_AS_NANO
  // mySoftwareSerial already connected to serial pins during object creation
  mySoftwareSerial.begin(9600); // this is Nano control to DFPlayer audio player
  if (!myDFPlayer.begin(mySoftwareSerial, false, true))
   // Nano uses SoftwareSerial to communicate with mp3 player
#endif // COMPILE_AS_NANO
  // if communications with myDFPlayer are not happy, report it and wait forever
  {
    Serial.println(F("Unable to begin DFPlayer:"));
    Serial.println(F("1.Please recheck the connection!"));
    Serial.println(F("2.Please insert the SD card!"));
    while(true){
      delay(1000); // wait forever; no recovery from this
    }
  }
} // end DFsetup_pins_serial()


#if MDO_USE_OTA // if using Over-The-Air software updates
/////////////////////////////////////////////////////////////////////////////////////////////////////////
// init_ota() - Over-The-Air software update - ESP32 only
//       returns: 0 if no error
//
//   start OTA
//
uint16_t init_ota() {

  // setup() already did START_OTA_WEB_BEGIN_WIFI
  mdo_ota_web_request(START_OTA_WEB_INIT_WIFI_STA | START_OTA_WEB_BEGIN_WIFI | START_OTA_WEB_INIT_MDNS | START_OTA_WEB_INIT_UPDATER_WEBPAGE);
  // after this, mdo_ota_web_loop() will handle it
  Serial.println("");
  Serial.print("WiFi OTA Connected to ");
  Serial.println(g_ssid);
  Serial.print("IP address: ");
  Serial.println(WiFi.localIP());
  Serial.printf("\nOTA Web Updater STARTED\n");

  return(0);
} // end init_ota()
#endif // MDO_USE_OTA if using Over-The-Air software updates

/////////////////////////////////////////////////////////////////////////////////////////////////////////
// ControlActive() - returns non-zero if control transitioned to LOW
//                   only returns non-zero again once until has transitioned to HIGH for at least MIN_DEBOUNCE_MSEC milliseconds
//
// p_dpin         - pin number to check for input
// p_idx_plus_one - the "sound" number associated with this pin
//
int ControlActive(int p_dpin, int p_idx_plus_one) {
  static uint32_t msec32_prev[SOUNDNUM_MAX_PLUS]; // initially zero
  static uint64_t msec64_control_countdown[SOUNDNUM_MAX_PLUS]; // initially zero
  static uint64_t msec64_now = 0;

  uint32_t msec32_now = millis();
  int ctl_state = digitalRead(p_dpin);
  int my_idx = p_idx_plus_one - 1;
  int my_ret = 0;


  // convert to 64-bit msec count so we "never" run out, not even after 49.7 days per 32-bit count
  if (msec32_now >= msec32_prev[my_idx]) {
    msec64_now += ((uint64_t) msec32_now) - ((uint64_t) msec32_prev[my_idx]);
  } else {
    // this happens about once every 49.7 days
    msec64_now +=  (0x100000000LL - ((uint64_t) msec32_prev[my_idx])) + ((uint64_t) msec32_now);
  }

  // if control is HIGH, keep track of the countdown. If countdown set to zero, we will flag next LOW
  if ((HIGH == ctl_state) && (msec64_now >= msec64_control_countdown[my_idx])) {
    // this is at least MIN_DEBOUNCE_MSEC after the last time we saw it LOW
    msec64_control_countdown[my_idx] = 0; // 
  }

  // if control is LOW and countdown is zero, we will return a 1 on this call
  if ((0 == msec64_control_countdown[my_idx]) && (LOW == ctl_state)) {
    // only return NON-ZERO if not waiting for debounce and LOW
    my_ret = 1; // first LOW since debounce; return TRUE
  }

  // if control is LOW, we alway update (extend) the countdown
  if  (LOW == ctl_state) {
    // always update the countdown if control state is LOW
    msec64_control_countdown[my_idx] =  msec64_now + ((uint64_t) MIN_DEBOUNCE_MSEC);
  }

  return(my_ret);
} // end ControlActive()

/////////////////////////////////////////////////////////////////////////////////////////////////////////
// setup()
void setup() {
  Serial.begin(115200);         // this serial communication is for general debug; set the USB serial port to 115,200 baud
  while (!Serial) {
    ; // wait for serial port to connect. Needed for native USB port only
  }
  delay(1000);
  Serial.println(""); // print a blank line in case there is some junk from power-on
  Serial.println("starting RingTheBell");

  // initialize the control pins; active LOW
  pinMode(DPIN_MALLET_HIT, INPUT_PULLUP);
  pinMode(DPIN_RING_BELL, INPUT_PULLUP);
#if MDO_USE_OTA // if using Over-The-Air software updates
  pinMode(DPIN_OTA, INPUT_PULLUP);
#endif // MDO_USE_OTA // if using Over-The-Air software updates

  // initialize the YX5200 DFPlayer audio player
  Serial.println("\nInitialize YX5200");
  DFsetup_pins_serial(); // this routine is inside this *.ino; has ESP32 and NANO specific code
  DFsetup(); // this routine is in lib_commonDFcode.cpp; sets up YX5200 for our method of operation
  // start the first sound, then allow normal loop() processing
  DFstartSound(SOUNDNUM_silence, SOUND_VOL_DEFAULT);
  Serial.println("  DFstartSound silence");

  Serial.println("\nRingTheBell init complete...");

} // end setup()

/////////////////////////////////////////////////////////////////////////////////////////////////////////
// loop()
//
void loop() {
  static uint16_t print_silence = 2;

  if (ControlActive(DPIN_MALLET_HIT, SOUNDNUM_MalletHit)) {
    DFstartSound(SOUNDNUM_MalletHit, SOUND_VOL_DEFAULT); // force sequence start
    Serial.println("  DFstartSound MalletHit");
    print_silence = 2;
  } else if (ControlActive(DPIN_RING_BELL, SOUNDNUM_RingBell)) {
    DFstartSound(SOUNDNUM_RingBell, SOUND_VOL_DEFAULT); // force sequence finish - expected prior to sound done
    Serial.println("  DFstartSound RingBell");
    print_silence = 2;
  } else if (DFcheckSoundDone()) {
    // next sound in sequence - silence
    if (0 != print_silence) {
      DFstartSound(SOUNDNUM_silence, SOUND_VOL_DEFAULT); // sequence to silence
      Serial.printf("  DFstartSound silence %d\n", print_silence);
      print_silence -= 1;
    }
  }

#if MDO_USE_OTA // if using Over-The-Air software updates
  static uint16_t ota_needs_init = 1;
  if ((ControlActive(DPIN_OTA, SOUNDNUM_save_for_OTA) || (FORCE_OTA_ON))  &&  ota_needs_init) {
    ota_needs_init = 0; // only do the init once
    init_ota();
  }

  // respond to OTA web server if there is user action
  if (0 == ota_needs_init) {
    mdo_ota_web_loop();
  }
#endif // MDO_USE_OTA if using Over-The-Air software updates

  // this delay should be less than one-half of MIN_DEBOUNCE_MSEC
  delay(LOOP_DELAY_MSEC);
} // end loop()

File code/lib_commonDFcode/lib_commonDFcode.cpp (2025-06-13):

// This ".h" file is actually C-code. Saves me the need to turn it into a true library.

/////////////////////////////////////////////////////////////////////////////////////////////////////////
#if DFPRINTDETAIL
void DFprintDetail(uint8_t type, int value){
  switch (type) {
    case TimeOut:
      Serial.println(F("Time Out!")); break;
    case WrongStack:
      Serial.println(F("Stack Wrong!")); break;
    case DFPlayerCardInserted:
      Serial.println(F("Card Inserted!")); break;
    case DFPlayerCardRemoved:
      Serial.println(F("Card Removed!")); break;
    case DFPlayerCardOnline:
      Serial.println(F("Card Online!")); break;
    case DFPlayerUSBInserted:
      Serial.println("USB Inserted!"); break;
    case DFPlayerUSBRemoved:
      Serial.println("USB Removed!"); break;
    case DFPlayerPlayFinished:
      Serial.print(F("Number:")); Serial.print(value); Serial.println(F(" Play Finished!"));  break;
    case DFPlayerError:
      Serial.print(F("DFPlayerError:"));
      switch (value) {
        case Busy:
          Serial.println(F("Card not found"));
          break;
        case Sleeping:
          Serial.println(F("Sleeping"));
          break;
        case SerialWrongStack:
          Serial.println(F("Get Wrong Stack"));
          break;
        case CheckSumNotMatch:
          Serial.println(F("Check Sum Not Match"));
          break;
        case FileIndexOut:
          Serial.println(F("File Index Out of Bound"));
          break;
        case FileMismatch:
          Serial.println(F("Cannot Find File"));
          break;
        case Advertise:
          Serial.println(F("In Advertise"));
          break;
        default:
          break;
      } // end switch (value)
      break;
    default:
      break;
  }  // end switch (type)
} // end DFprintDetail()
#endif // DFPRINTDETAIL

/////////////////////////////////////////////////////////////////////////////////////////////////////////
// DFstartSound(p_SoundNum, p_Volume) - start p_SoundNum if it is valid
//
// p_SoundNum is the sound file number, range 1 to SOUNDNUM_MAX_VALID
// p_Volume   is the requested vol, range 0 to 30
//
// Had lots of trouble with reliable operation using playMp3Folder. Came to conclusion
//    that it is best to use the most primitive of YX5200 commands.
// Also saw strong correlation of using YX5200 ACK and having even more unreliable
//    operation, so turned that off in DFinit.
// The code checking DPIN_AUDIO_BUSY still needs the delay but 200 millisec is probably overkill.
// There is code checking myDFPlayer.available() that can maybe also be removed now
//    that the dubugging for above is finished. Now that I am using myDFPlayer.play(),
//    it only seems to trigger when I interrupt a playing sound by starting another.
//    It is sort of interesting but not needed.
//
void  DFstartSound(uint16_t p_SoundNum, uint16_t p_Volume) {
  uint16_t idx;
  bool prevHI;
  uint16_t my_SoundNum = p_SoundNum;
  static uint8_t init_minmax = 2;
  static uint32_t prev_msec;
  static uint32_t max_msec = 0;
  static uint32_t min_msec = 999999;
  uint32_t diff_msec = 0;
  uint32_t now_msec = millis();

#if DFPRINTDETAIL
  if (myDFPlayer.available()) {
    Serial.print(F(" DFstartSound ln ")); Serial.print((uint16_t) __LINE__); Serial.println(F(" myDFPlayer problem after volume"));
    DFprintDetail(myDFPlayer.readType(), myDFPlayer.read()); //Print the detail message from DFPlayer to handle different errors and states.
  }
#endif // DFPRINTDETAIL

  myDFPlayer.volume(p_Volume);  // Set volume value. Range from 0 to 30
  myDFPlayer.play(my_SoundNum); //play specific wav in SD: root directory ###.wav; number played is physical copy order; first one copied is 1
  // Serial.print(F("DEBUG DFstartSound myDFPlayer.play(")); Serial.print((uint16_t) my_SoundNum); Serial.println(F(")"));
  gTimerForceSoundActv = millis() + SOUND_ACTIVE_PROTECT; // handle YX5200 problem with interrupting play

  if (init_minmax) {
    init_minmax -= 1;
  }  else {
    diff_msec = now_msec - prev_msec;
    if (diff_msec > max_msec) {
      max_msec = diff_msec;
      // Serial.print(F("max_msec ")); Serial.println(max_msec);
    } else if (diff_msec < min_msec) {
      min_msec = diff_msec;
      // Serial.print(F("min_msec ")); Serial.println(min_msec);
    }
  }
  prev_msec = now_msec;
} // end DFstartSound()

/////////////////////////////////////////////////////////////////////////////////////////////////////////
// DFcheckSoundDone() - returns TRUE if previous sound is complete (DFPlayer/YX5200 is notBusy)
//
// notBusy means (HIGH == digitalRead(DPIN_AUDIO_BUSY)) && (millis() >= gTimerForceSoundActv)
//
//    DPIN_AUDIO_BUSY goes HIGH when sound finished, but may take a while to start being high after sound starts
//    gTimerForceSoundActv is millisec count we have to wait for to before checking DPIN_AUDIO_BUSY
//    so we have to be BOTH (DPIN_AUDIO_BUSY is HIGH) AND (current time is beyond gTimerForceSoundActv)
//
uint8_t DFcheckSoundDone() {
  return (HIGH == digitalRead(DPIN_AUDIO_BUSY)) && (millis() >= gTimerForceSoundActv);
} // end DFcheckSoundDone()

/////////////////////////////////////////////////////////////////////////////////////////////////////////
// DFsetup()
void DFsetup() {
  Serial.println(F("Initializing DFPlayer ... (May take 3~5 seconds)"));
  
  myDFPlayer.EQ(DFPLAYER_EQ_BASS); // our speaker is quite small
  myDFPlayer.outputDevice(DFPLAYER_DEVICE_SD); // location of sound files is MicroSD card
  myDFPlayer.volume(SOUND_VOL_MAX);  // Set volume value. From 0 to 30 - FIXME 25 is good
  // delay(3000); // allow bluetooth connection to complete - not using bluetooth; tinny sound from small speaker adds to effect
  delay(1000); // allow DFPlayer to stabilize
  Serial.println(F("DFPlayer Mini online."));

} // end DFsetup()

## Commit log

2025-06-13 Moving towards one codebase for both ESP32 and NANO
2025-06-13 first cut at schematic
    [RingTheBell.kicad_sch]
2025-06-14 fix error in ESP32 TX/RX
    [RingTheBell.kicad_sch]
2025-06-15 add some debug print statements
2025-06-19 Various flavors of voltage levels
    [74HCT125N.kicad_sch, RingTheBell.kicad_sch]
2025-06-20 tighten up the schematics
    [3.3V.kicad_sch, 3.3V_UART.kicad_sch, 74HCT125N.kicad_sch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]
